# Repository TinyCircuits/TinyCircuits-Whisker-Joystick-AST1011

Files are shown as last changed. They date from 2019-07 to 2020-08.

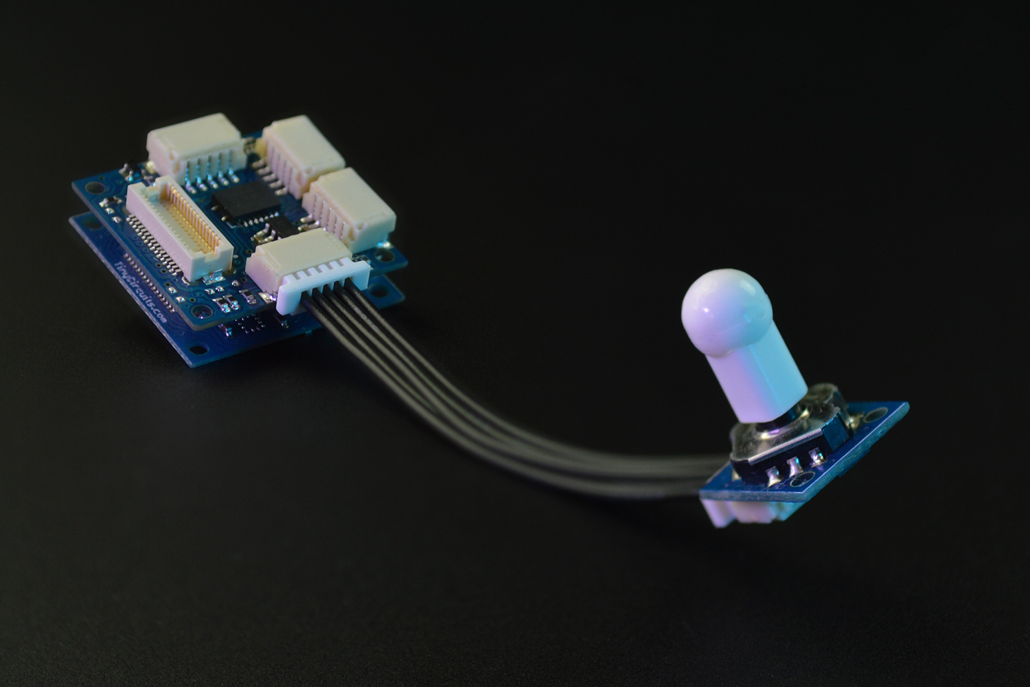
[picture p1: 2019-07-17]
images/AST1011-Tutorial-Image-03.jpg

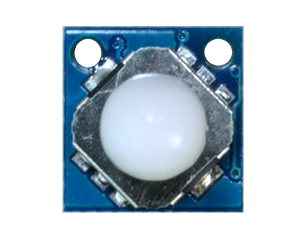
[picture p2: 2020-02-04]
images/AST1011-Tutorial-Image-01.png

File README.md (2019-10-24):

# TinyCircuits Wireling Joystick
# AST1011 Rev2

The design files are located under design_files/ for the TinyCircuits AST1011 Rev 2 PCB. This is a Wireling board which lets you use a discrete joystick for four directional inputs to your TinyDuino! This Up, Down, Left, Right joystick outputs data to an SX1502 I2C I/O expander. This data can then acquired by the main processor via I2C.
Format is in Cadsoft Eagle format - Eagle version 6.2 was used for the original design.

For more infomation on this, check out the product page at TinyCircuits.com

# License:

Design by TinyCircuits.
All design files are released under the Creative Commons Attribution Share-Alike 3.0 License, see the following link for details: http://creativecommons.org/licenses/by-sa/3.0

All text above must be included in any redistribution or derived design

This project uses designs and concepts developed as part of the Arduino project and the LilyPad project.  The TinyCircuits design files themselves (schematics, PCB and libraries) are not directly derived from these works' design files and have been created new, however the concepts and basic architecture behind the TinyDuino and TinyLily products are derived and we thank the hard work of the organizations below for their contributions to open-source hardware:
  
Original Arduino Uno Design by Team Arduino

LilyPad Arduino Design by Leah Buechley and Sparkfun Electronics

Please support the open-source hardware community

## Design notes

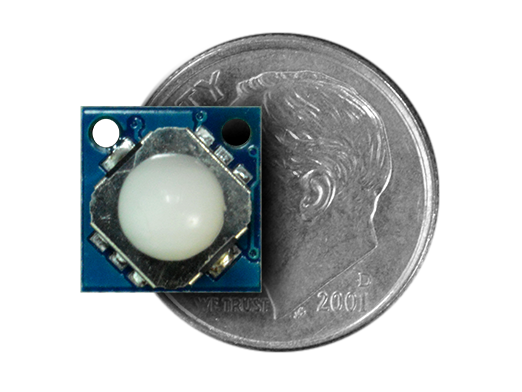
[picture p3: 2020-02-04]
images/AST1011-Product-Photo-03.png

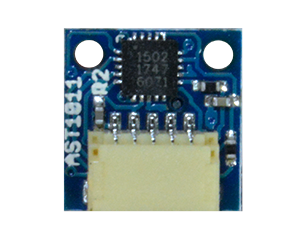
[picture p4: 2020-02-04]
images/AST1011-Learn-Photo-02.png

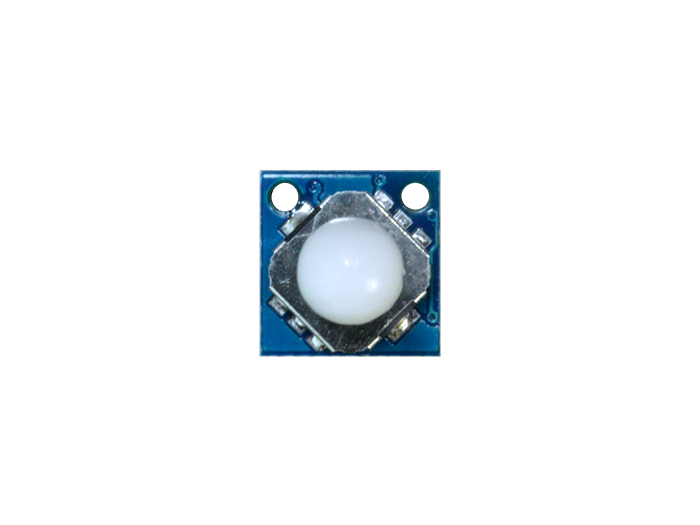
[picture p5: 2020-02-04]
images/AST1011-Product-Image-01.png

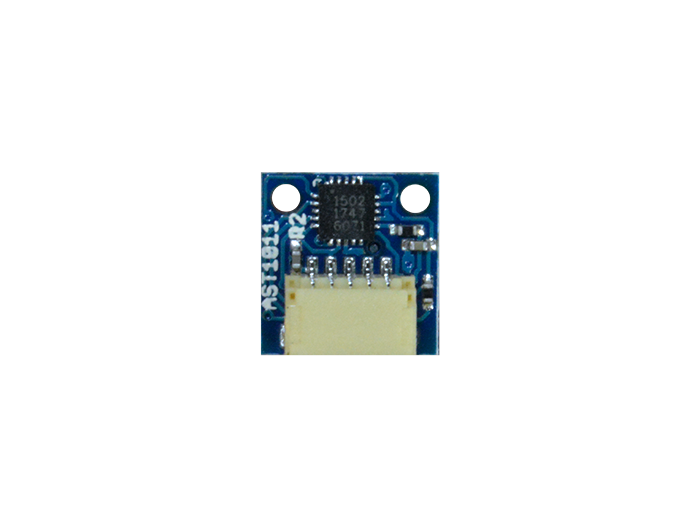
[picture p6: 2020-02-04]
images/AST1011-Product-Photo-02.png

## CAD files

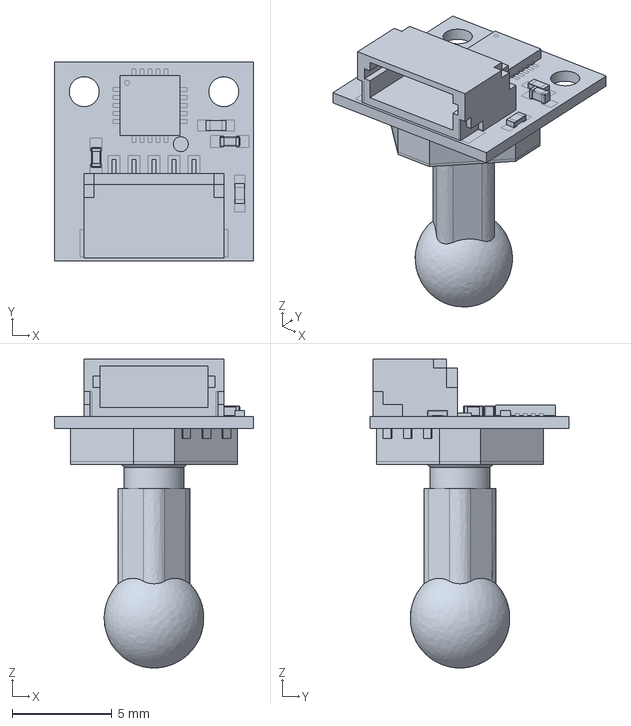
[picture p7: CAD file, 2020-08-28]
cad/Wireling_JOYSTICK_AST1011_REV2-IGES.iges
10.0 x 10.0 x 15.5 mm

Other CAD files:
cad/Wireling_JOYSTICK_AST1011_REV2-DETAILED_DRAWING-DXF.dxf
cad/Wireling_JOYSTICK_AST1011_REV2-STEP.step

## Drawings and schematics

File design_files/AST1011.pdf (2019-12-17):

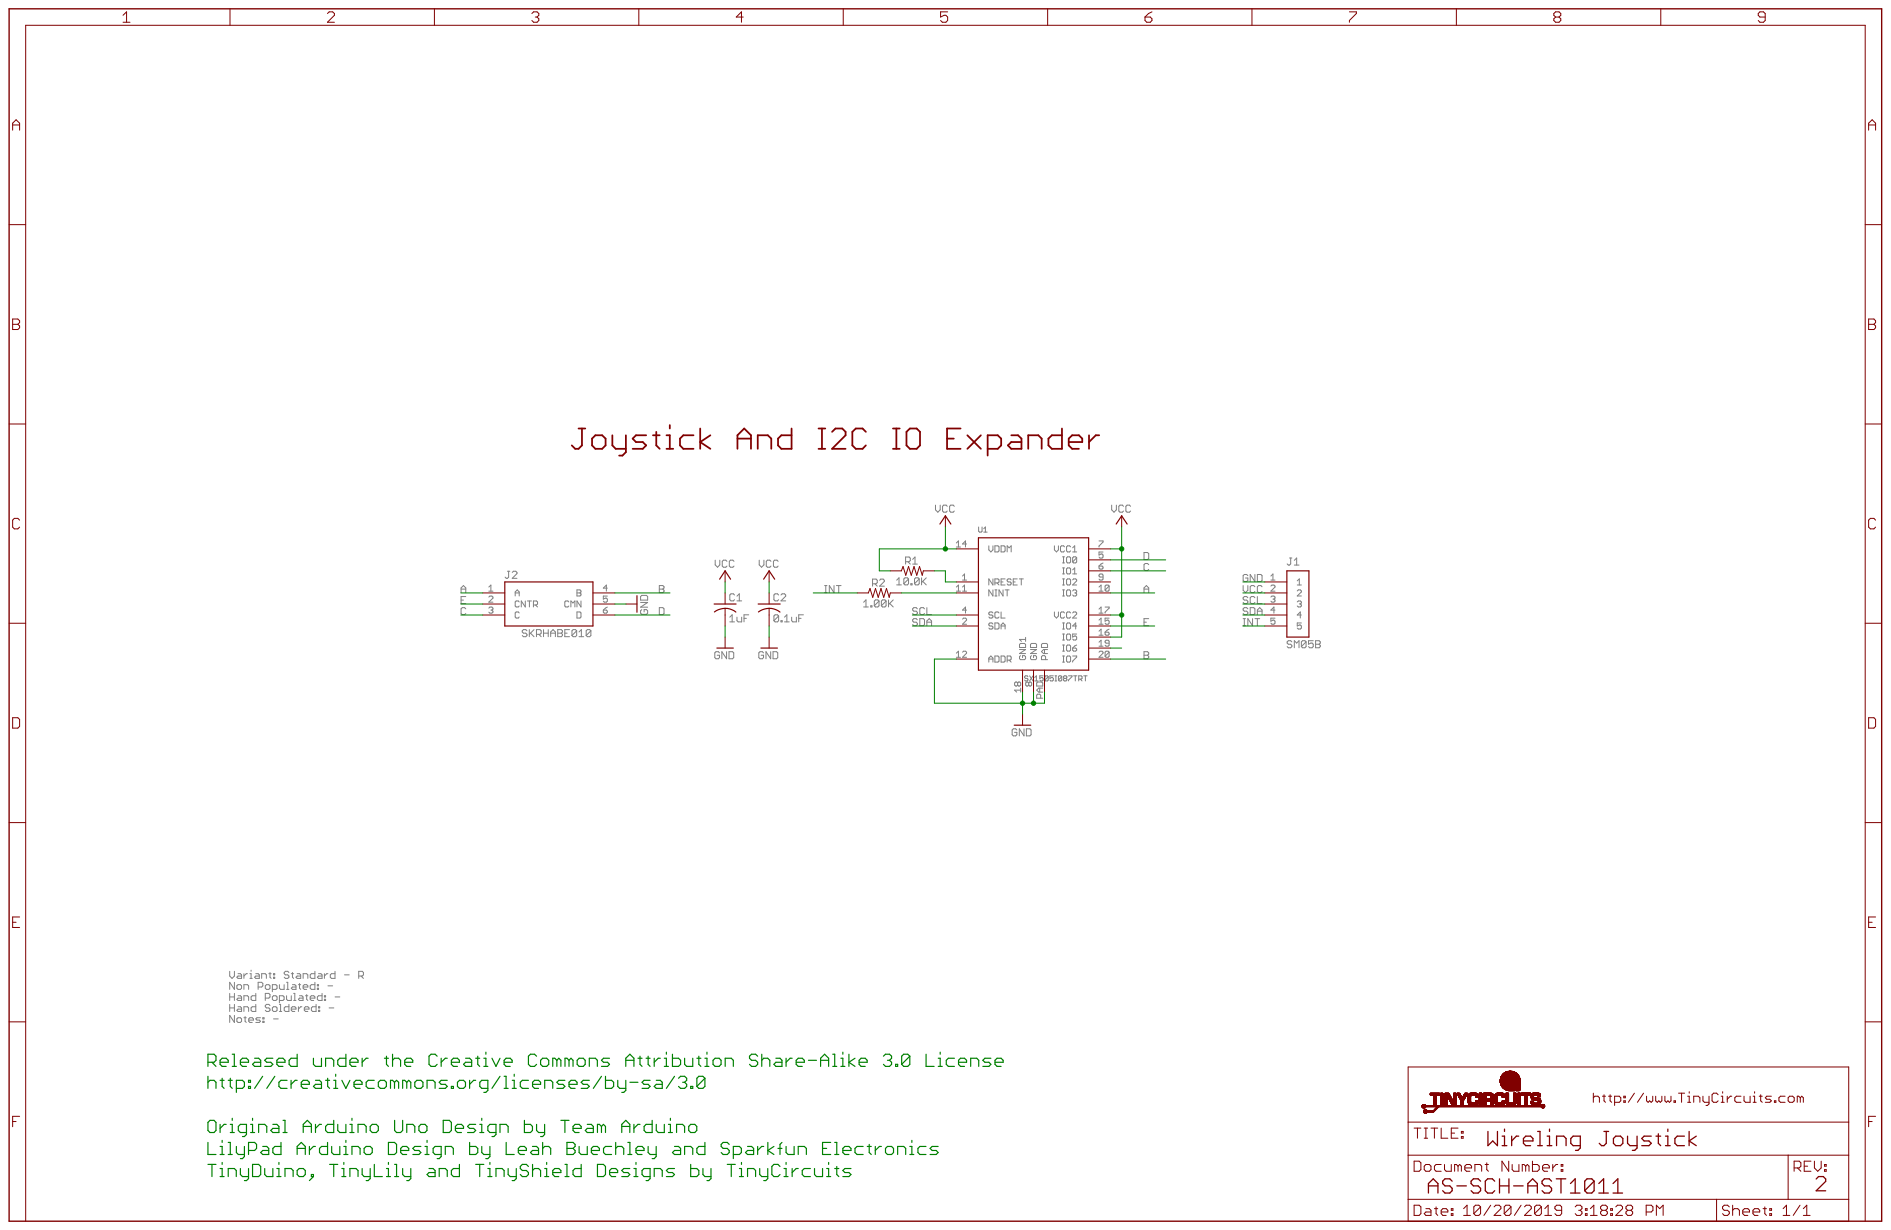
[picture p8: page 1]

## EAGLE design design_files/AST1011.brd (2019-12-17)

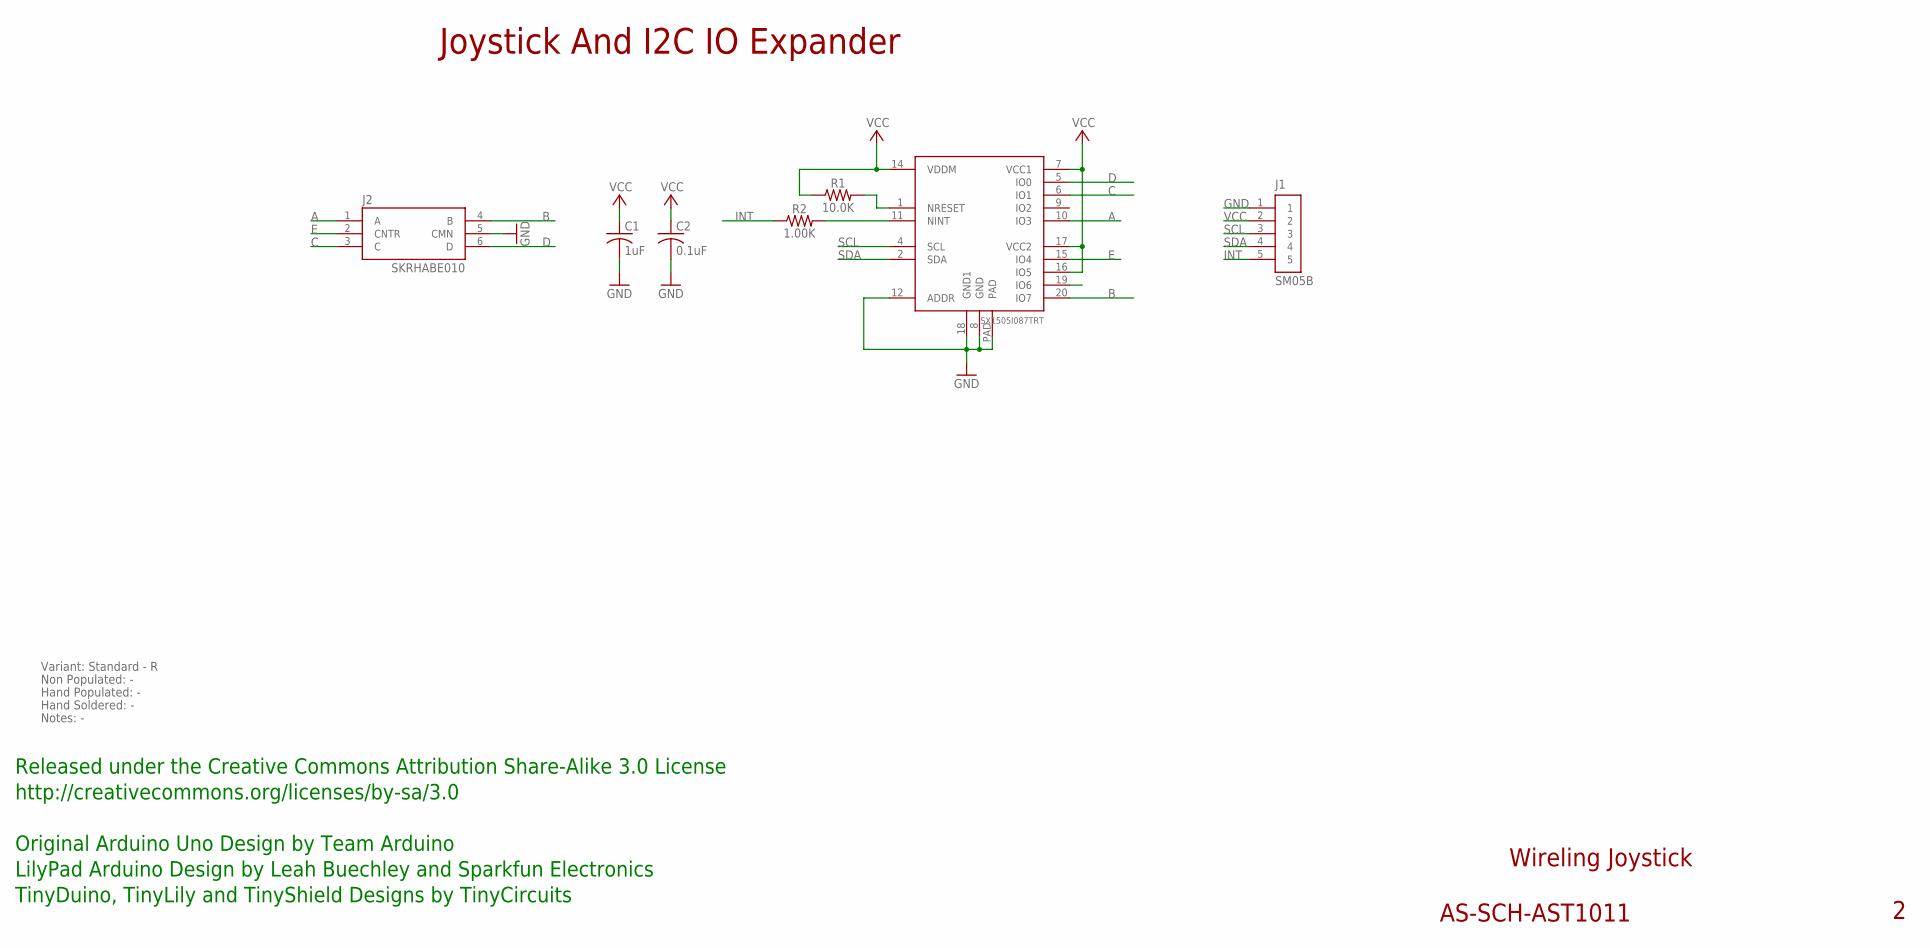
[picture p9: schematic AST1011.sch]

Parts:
C1: 1uF; C0402; PARTNO AS-ITM-00105
C2: 0.1uF; C0402
J1: SM05B; JST_SH_5X1_EDGE
J2: SKRHABE010; SKRHA_C
R1: 10.0K; 0402
R2: 1.00K; 0402
U1: SX1505I087TRT; QFN-UT20

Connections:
A: J2.1 (A), U1.10 (IO3)
B: J2.4 (B), U1.20 (IO7)
C: J2.3 (C), U1.6 (IO1)
D: J2.6 (D), U1.5 (IO0)
E: J2.2 (CNTR), U1.15 (IO4)
GND: C1.2, C2.2, J1.1, J2.5 (CMN), U1.8 (GND), U1.12 (ADDR), U1.18 (GND1), U1.PAD
INT: J1.5, R2.1
unnamed: R2.2, U1.11 (NINT)
unnamed: R1.2, U1.1 (NRESET)
SCL: J1.3, U1.4 (SCL)
SDA: J1.4, U1.2 (SDA)
VCC: C1.1, C2.1, J1.2, R1.1, U1.7 (VCC1), U1.14 (VDDM), U1.16 (IO5), U1.17 (VCC2)

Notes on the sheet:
Wireling Joystick
AS-SCH-AST1011
Joystick And I2C IO Expander
Released under the Creative Commons Attribution Share-Alike 3.0 License
http://creativecommons.org/licenses/by-sa/3.0
Original Arduino Uno Design by Team Arduino
TinyDuino, TinyLily and TinyShield Designs by TinyCircuits
LilyPad Arduino Design by Leah Buechley and Sparkfun Electronics
Non Populated: -
Hand Populated: -
Hand Soldered: -
Variant: Standard - R
Notes: -

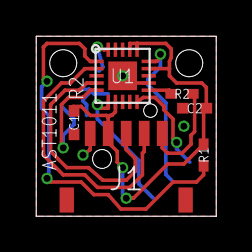
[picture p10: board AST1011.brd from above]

Board: 2 copper layers, 10.0 x 10.0 mm, 8 parts (1 on the bottom side), 12 nets.

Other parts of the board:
U$1: DOCFIELD-TINYCIRCUITS-PCB

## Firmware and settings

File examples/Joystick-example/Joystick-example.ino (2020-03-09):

/*
  Joystick Example
  Prints to the Serial Monitor the direction the joystick is moved in (Up, down, left, right)
  The "up" direction is the direction closest to the 5-pin connector.

  Written by: Laveréna Wienclaw for TinyCircuits
  Last Updated: March 2020
*/

#include <Wire.h>
#include <Wireling.h>
#include <SX1505.h>             // For interfacing with Joystick and Rotary Switch Wirelings

// Universal TinyCircuits Serial Monitor Config
#if defined (ARDUINO_ARCH_AVR)
#define SerialMonitorInterface Serial
#elif defined(ARDUINO_ARCH_SAMD)
#define SerialMonitorInterface SerialUSB
#endif

/* * * * * * * * * * Joystick * * * * * * * * * */
#define JS_PORT 0
TinyJoystick joystick = TinyJoystick(); 

void setup() {
  Wire.begin();
  Wireling.begin();

  /* * * * * * Joystick Init * * * * */
  Wireling.selectPort(JS_PORT); 
  joystick.begin(); 
  
  SerialMonitorInterface.begin(9600);
  delay(500);
}

void loop() {
  joystick.getPosition();
  writeToMonitor();
}

void writeToMonitor() {

  if(joystick.up) {
    SerialMonitorInterface.println("UP (direction facing 5-pin connector)");
  }
  else if(joystick.down) {
    SerialMonitorInterface.println("DOWN");
  }
  else if(joystick.left) {
    SerialMonitorInterface.println("LEFT");
  }
  else if(joystick.right) {
    SerialMonitorInterface.println("RIGHT");
  }
  delay(100);
}

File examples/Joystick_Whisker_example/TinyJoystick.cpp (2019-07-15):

#include "TinyJoystick.h"

#include <inttypes.h>
#include "Arduino.h"
#include <Wire.h>

TinyJoystick::TinyJoystick() {
  // default constructor
}

int TinyJoystick::begin() {
  //Detect address
  I2Caddress = SX1505_I2CADDR;
  Wire.beginTransmission(I2Caddress);
  if (Wire.endTransmission()) {         // if data is too long or ERROR
    I2Caddress++;                       // increment address
    Wire.beginTransmission(I2Caddress); // write to new address (the next address)
    if (Wire.endTransmission()) {       // if data is too long or ERROR
      I2Caddress = 0;                   // set address to 0
      return -1;                        // return -1 to indicate an error
    }             // better to return value given by Wire.endTransmission?
  }
  return 0;       // return 0 to indicate that the first transmission succeeded
}

// writes byte "regData" to register "regAddr"
void TinyJoystick::write(uint8_t regAddr, uint8_t regData) {
  Wire.beginTransmission(SX1505_I2CADDR);
  Wire.write(regAddr);
  Wire.write(regData);
  Wire.endTransmission();
}

// returns byte stored within specified register
uint8_t TinyJoystick::read(uint8_t regAddr) {
  Wire.beginTransmission(SX1505_I2CADDR);
  Wire.write(regAddr);
  debug = Wire.endTransmission(); // debug set to value returned (error checking)

  // Request one data byte
  Wire.requestFrom(SX1505_I2CADDR, 1);
  
  value = (uint8_t)Wire.read();
}

// initialize SX1505 for use with SH7010
int TinyJoystick::init(void) {
  write(SX1505_REGDIR, 0xFF);           // set I/O to all input
    delay(5);
  write(SX1505_REG_PLD_MODE, 0x00);     // disable PLD input (default)
    delay(5);
  write(SX1505_REG_DATA, 0x00);         // clear contents of register data
    delay(5);
  write(SX1505_REG_PULLUP, 0x9B);       // enable pull-up on IO3, 7, 1, 0, 4 (IO used by Joystick)
    delay(5);
  return debug;
}

// return data from data register
uint8_t TinyJoystick::getRegData(void) {
  value = 0x00;
  value = read(SX1505_REG_DATA);
  return value;
}

// return joystick position
void TinyJoystick::getPosition(void) {
  getRegData();

  uint8_t dirtyValue = ~value;  // flip bits since active low
  
  if(dirtyValue & JOYSTICK_UP) {
    up = 1;
  }
  if(dirtyValue & JOYSTICK_DOWN) {
    down = 1;
  }
  if(dirtyValue & JOYSTICK_LEFT) {
    left = 1;
  }
  if(dirtyValue & JOYSTICK_RIGHT) {
    right = 1;
  }
  if (dirtyValue == JOYSTICK_NEUTRAL){
    up = 0;
    down = 0;
    left = 0;
    right = 0;
  }
}

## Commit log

2019-12-17 updated documentation
    [AST1011.brd, AST1011.sch]
2020-08-28 Add CAD data
    [Wireling_JOYSTICK_AST1011_REV2-DETAILED_DRAWING-DXF.dxf, Wireling_JOYSTICK_AST1011_REV2-IGES.iges, Wireling_JOYSTICK_AST1011_REV2-STEP.step]
